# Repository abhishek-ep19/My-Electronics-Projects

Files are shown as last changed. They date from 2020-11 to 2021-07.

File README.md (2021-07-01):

# Student Researched And Developed(SRAD) RF Transceiver
This is a project on design of a SRAD RF Transceiver which was made as a part of avionics team,Sounding Rocket, IIT Madras. This was designed using nRF905 RFIC and uses SPI AND I2C protocol. It operates on frequency 433 MHz which is operable in United States. Due to its low frequency we would be able to use an optimal length of antenna for communication at large distances and 10000 ft. at which rocket will attain its maximum height is well in its range above the ground.
This was made using Autodesk EAGLE and contains the borad design and schematics. Along with it this repository also contains nRF905 RFIC manual.

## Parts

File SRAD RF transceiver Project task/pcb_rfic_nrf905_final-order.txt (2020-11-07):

Order list for C:/Users/DELL/OneDrive/Documents/EAGLE/projects/Transceiver_module/pcb_rfic_nrf905_final.sch
Exported from EAGLE with DesignLink

Quantity	Value	Package	Order code	Manufacturer	Manuf. Code	Availability	Price (from)	Description
2	15 pF	C0603	03AC2905	MULTICOMP PRO	MCMT18N150F500CT	8000	0.022	MULTICOMP PRO - MCMT18N150F500CT - SMD Multilayer Ceramic Capacitor, 15 pF, 50 V, 0603 [1608 Metric], ± 1%, C0G / NP0
3	33pF	C0603	03AC2918	MULTICOMP PRO	MCMT18N330F100CT	16000	0.022	MULTICOMP PRO - MCMT18N330F100CT - SMD Multilayer Ceramic Capacitor, 33 pF, 10 V, 0603 [1608 Metric], ± 1%, C0G / NP0
1	3.3nF	C0603	01AC8337	KEMET	C0603C332J5JACTU	369	0.083	KEMET - C0603C332J5JACTU - CAP, 3300PF, 50V, 5%, U2J, 0603
1	4.7nF	C0603	01AC1585	KEMET	C0603X472K5RAC3316	12258	0.104	KEMET - C0603X472K5RAC3316 - CAP, 4700PF, 50V, 10%, X7R, 0603
1	10nF	C0603	04X3152	TDK	CGA3E2C0G1H103J080AA	3760	0.08	TDK - CGA3E2C0G1H103J080AA - SMD Multilayer Ceramic Capacitor, 10000 pF, 50 V, 0603 [1608 Metric], &#177; 5%, C0G / NP0, CGA Series
1	33 pF	C0603	64K2857	KEMET	C0603C330J5GACTU	167635	0.051	KEMET - C0603C330J5GACTU - SMD Multilayer Ceramic Capacitor, 33 pF, 50 V, 0603 [1608 Metric], &#177; 5%, C0G / NP0, C Series KEMET
2	3.9 pF	C0603	10AH1929	AVX	06035A3R9DAT2A	44000	0.006	AVX - 06035A3R9DAT2A - CAP 3.9PF 50VDC C0G 0.5PF SMD 0603 ROHS COMPLIANT: YES
2		C0603	unknown					
1		1X01	48W3690	VISHAY	VO615A-1X019T	1432	0.133	VISHAY - VO615A-1X019T - Transistor Output Optocoupler, Low Input Current, 1, 5 kV, 40 %, 60 mA, Surface Mount DIP, 4 RoHS Compliant: Yes
1		LQFP-32	unknown					
1		1X02	unknown					
3	12nH	0204V	10R8619	MULTICOMP PRO	MCFT000084	8520	0.03	MULTICOMP PRO - MCFT000084 - High Frequency Inductor, 12 nH, MCFT Series, 700 mA, 0603 [1608 Metric], Wirewound, 0.13 ohm
1	16 MHz	HC18U-V	unknown					
1	1 Mohm	R0603	01Y7500	MULTICOMP PRO	MCWR06X1004FTL	114744	0.001	MULTICOMP PRO - MCWR06X1004FTL - SMD Chip Resistor, 1 Mohm, ± 1%, 100 mW, 0603 [1608 Metric], Thick Film, General Purpose
1	22 Kohm	R0603	unknown					
3	10 Kohm	R0603	unknown					
1	MOLEX_SL_16-70543-74095	SL_70543_16	unknown					
1	ZX62D-B-5PA8	ZX62D-B-5PA8	unknown	Hirose	ZX62D-B-5PA8			
1		SMA_EDGELAUNCH	unknown

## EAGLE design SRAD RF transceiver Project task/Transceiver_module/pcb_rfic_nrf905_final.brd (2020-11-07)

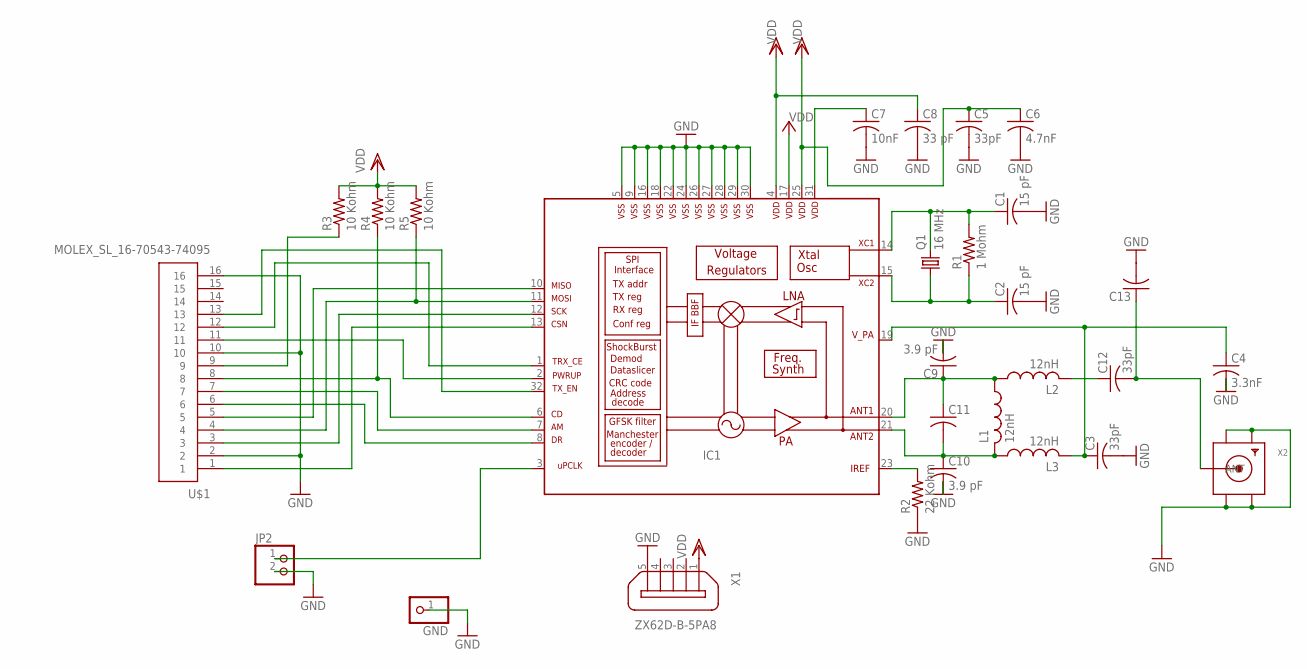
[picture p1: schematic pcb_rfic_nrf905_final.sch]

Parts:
C1, C2: 15 pF; C0603; MPN MCMT18N150F500CT
C3, C5, C12: 33pF; C0603; MPN MCMT18N330F100CT
C4: 3.3nF; C0603; MPN C0603C332J5JACTU
C6: 4.7nF; C0603; MPN C0603X472K5RAC3316
C7: 10nF; C0603; MPN CGA3E2C0G1H103J080AA
C8: 33 pF; C0603; MPN C0603C330J5GACTU
C9, C10: 3.9 pF; C0603; MPN 06035A3R9DAT2A
C11, C13: C-USC0603; C0603
GND: PINHD-1X1; 1X01; MPN VO615A-1X019T
IC1: NRF905; LQFP-32
JP2: PINHD-1X2; 1X02
L1, L2, L3: 12nH; 0204V; MPN MCFT000084
Q1: 16 MHz; HC18U-V
R1: 1 Mohm; R0603; MPN MCWR06X1004FTL
R2: 22 Kohm; R0603
R3, R4, R5: 10 Kohm; R0603
U$1: MOLEX_SL_16-70543-74095; SL_70543_16
X1: ZX62D-B-5PA8
X2: SMACONNECTOR_EDGE; SMA_EDGELAUNCH

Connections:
GND: C1.2, C2.2, C3.2, C4.2, C5.2, C6.2, C7.2, C8.2, C9.2, C10.2, C13.2, GND.1, IC1.5 (VSS5), IC1.9 (VSS9), IC1.16 (VSS16), IC1.18 (VSS18), IC1.22 (VSS22), IC1.24 (VSS24), IC1.26 (VSS26), IC1.27 (VSS27), IC1.28 (VSS28), IC1.29 (VSS29), IC1.30 (VSS30), JP2.2, R2.1, U$1.2, U$1.10, U$1.16, X1.5, X2.GND@1 (GND4), X2.GND@2 (GND3), X2.GND@3 (GND2), X2.GND@4 (GND1)
unnamed: C1.1, IC1.14 (XC1), Q1.2, R1.2
unnamed: C2.1, IC1.15 (XC2), Q1.1, R1.1
unnamed: IC1.23 (IREF), R2.2
unnamed: C7.1, IC1.31 (DVDD1V2)
unnamed: C9.1, C11.1, IC1.20 (ANT1), L1.1, L2.1
unnamed: C10.1, C11.2, IC1.21 (ANT2), L1.2, L3.1
unnamed: C12.1, L2.2
unnamed: C3.1, C4.1, IC1.19 (VDD_PA), L3.2
unnamed: IC1.10 (MISO), U$1.5
unnamed: IC1.11 (MOSI), R5.1, U$1.4
unnamed: IC1.12 (SCK), U$1.3
unnamed: R3.1, U$1.9
unnamed: IC1.1 (TRX_CE), U$1.12
unnamed: IC1.2 (PWR_UP), U$1.11
unnamed: IC1.32 (TX_EN), U$1.13
unnamed: IC1.6 (CD), R4.1, U$1.8
unnamed: IC1.7 (AM), U$1.7
unnamed: IC1.8 (DR), U$1.6
unnamed: IC1.3 (UPCLK), JP2.1
unnamed: IC1.13 (CSN), U$1.1
unnamed: C12.2, C13.1, X2.P (ANT)
VCC: IC1.17 (VDD17)
VDD: C5.1, C6.1, C8.1, IC1.4 (VDD4), IC1.25 (VDD25), R3.2, R4.2, R5.2, X1.1

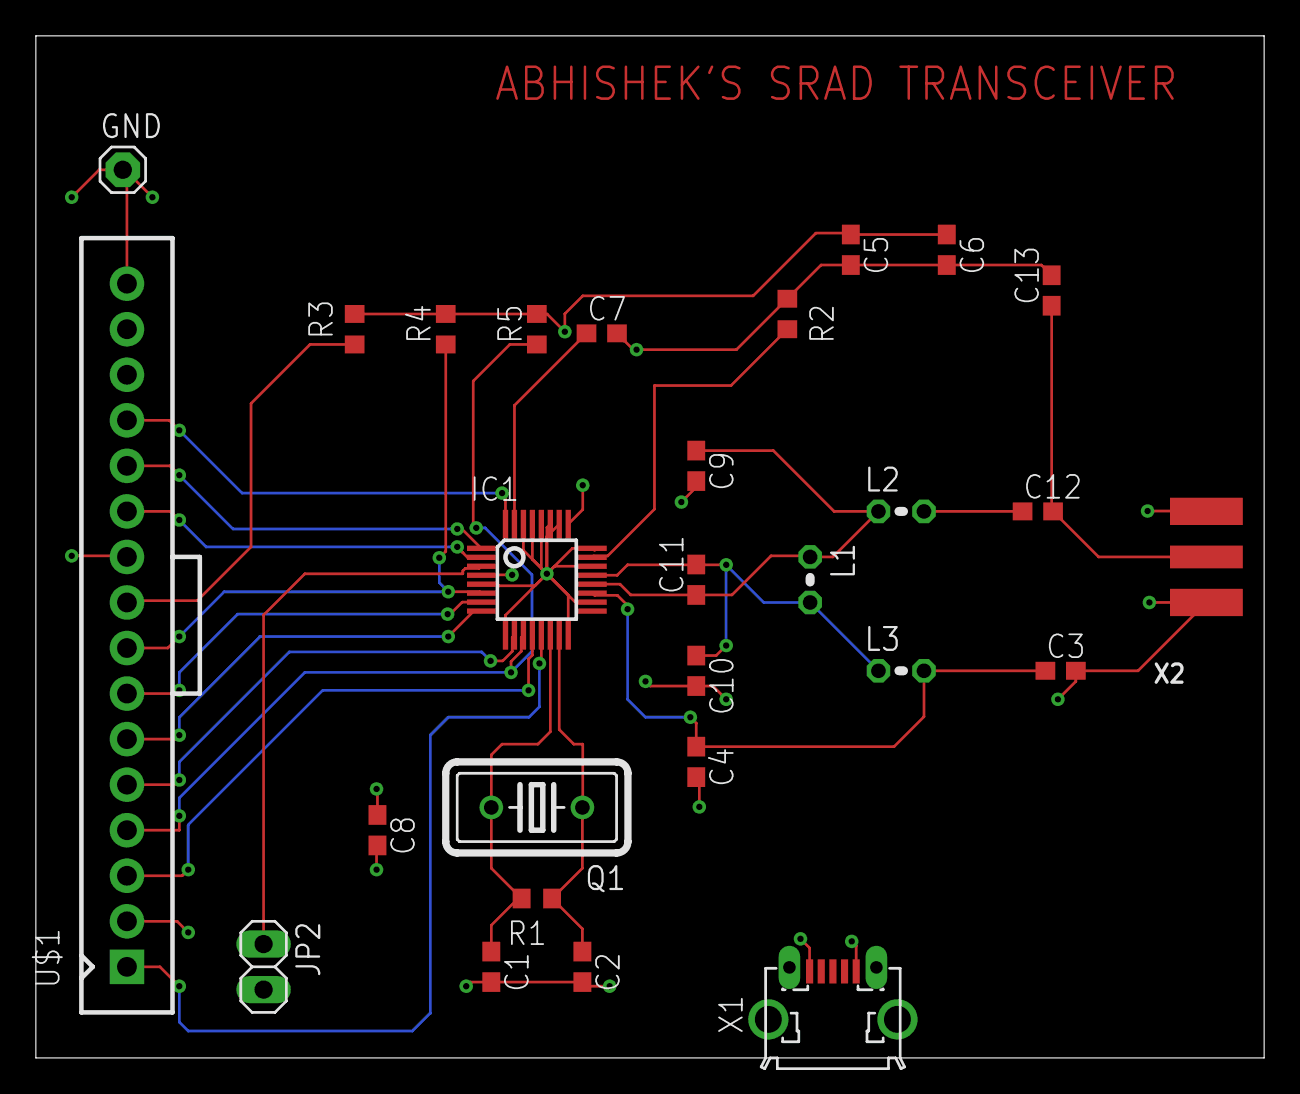
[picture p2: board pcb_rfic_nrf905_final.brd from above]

Board: 4 copper layers, 68.5 x 57.0 mm, 28 parts (0 on the bottom side), 23 nets.
